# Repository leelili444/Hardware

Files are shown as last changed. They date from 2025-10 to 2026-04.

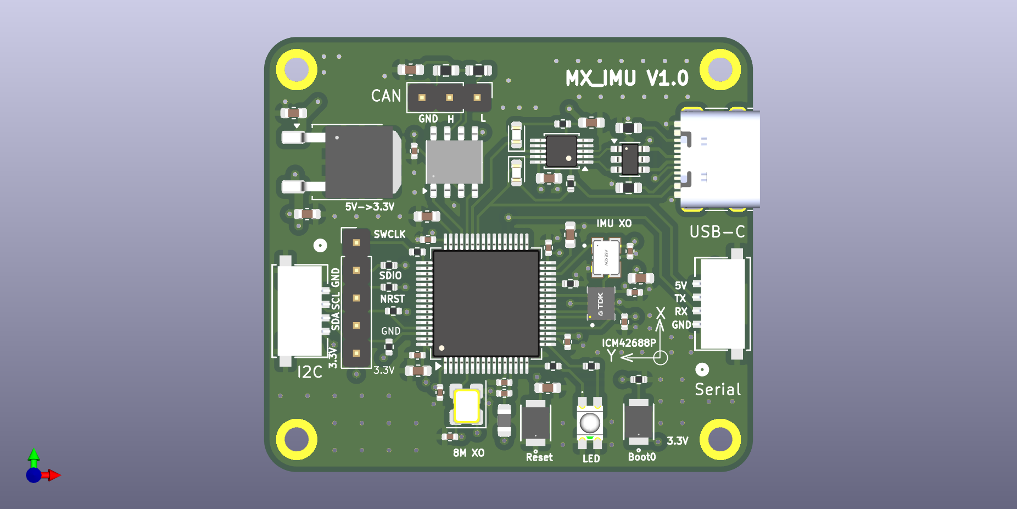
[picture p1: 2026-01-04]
production/MX_IMU.png

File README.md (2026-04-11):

# MX_IMU Hardware Design (using KiCad 9)

This repository contains the MX_IMU V1.0 hardware design files, libraries, and production outputs created with KiCad.

## Overview

- Project: MX_IMU (IMU sensor module)
- Tool: KiCad (schematic capture and PCB layout)

## Key Files

- `MX_IMU.kicad_pro` - Project file
- `MX_IMU.kicad_sch` — Main schematic
- `MX_IMU.kicad_pcb` — PCB layout file
- `*.kicad_sym` — Symbol files, located in `library/symbols`
- `*.kicad_mod` (footprints) — Footprint libraries, located in `library/footprints`
- `3DModels/` — Component 3D STEP models for the PCB 3D viewer
- `production/` — Manufacturing outputs (BOM, placement files, IPC netlist, etc.)

## How to Open

1. Install KiCad on your computer (stable or LTS versions recommended).
2. Open the project via `File -> Open Project` and select `MX_IMU.kicad_pro`, or open `MX_IMU.kicad_sch` / `MX_IMU.kicad_pcb` directly.

## Libraries and 3D Models

- Custom symbols: `library/symbols`.
- Custom footprints: `library/footprints` (contained in `.pretty` directories).
- 3D STEP files: `library/3DModels` for the PCB 3D viewer and manufacturing visualization.

## Production Directory

The `production/` directory includes `bom.csv`, `positions.csv` (placement), `netlist.ipc`, and similar files that can be used for ordering or manufacturing.
## License
oshw_facts

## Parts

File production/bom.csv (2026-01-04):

Designator | Footprint | Quantity | Value | LCSC Part #
C1, C16, C3 | 0603 | 3 | 100nf
C10, C11, C12, C15, C21, C7, C9 | 0402 | 7 | 100n | C1525
C13 | 0402 | 1 | 1u | C52923
C14 | 0402 | 1 | 10n | C15195
C17 | 0402 | 1 | 0.01u
C18 | 0402 | 1 | 0.1u
C19, C4, C6, C8 | 0603 | 4 | 2u2 | C23630
C2 | 0603 | 1 | 1u
C20 | 0402 | 1 | 10n
C22 | 0603 | 1 | 4n7
C5 | 0603 | 1 | 4u7 | C19666
D1, D2 | 0603 | 2 | LED
FB1 | 0805 | 1 | 600 @ 600 MHz | C1017
H1, H2, H3, H4 | MountingHole_2.2mm_M2_DIN965_Pad | 4 | MountingHole_Pad
I2C1, SERIAL1 | CONN_SM04B-GHS-TB_JST | 2 | SM04B-GHS-TB(LF)(SN)
J1 | USB_C_Receptacle_HRO_TYPE-C-31-M-12 | 1 | Serial USB
J2 | PinHeader_1x05_P2.54mm_Vertical | 1 | ZX-PZ2.54-1-5PZZ
J3 | PinHeader_1x03_P2.54mm_Vertical | 1 | Conn_01x03_Socket
LED1 | APBD3224SURKCGKCF01 | 1 | APBD3224SURKCGKC-F01
LSE1 | XTAL_ASEK-32.768KHZ-L-R-T | 1 | ASEK-32.768KHZ-L-R-T
R1, R2, R7, R8 | 0402 | 4 | 330R | C25104
R10, R11, R9 | 0402 | 3 | 22 | C25092
R12, R13 | 0603 | 2 | 60R | C166918
R14, R15 | 0402 | 2 | 2k2
R3, R4 | 0603 | 2 | 5.1k
R5, R6 | 0402 | 2 | 10k | C25744
SW1, SW2 | SW_B3U-1000P_OMR | 2 | B3U-1000P | C231329
U1 | MSOP-10_3x3mm_P0.5mm | 1 | CH340E
U2 | to-252-2_dpak-2-leg | 1 | ld39150dt33-r
U3 | SOT-23-6 | 1 | USBLC6-2SC6
U4 | LQFP-64_10x10mm_P0.5mm | 1 | STM32F405RGTx | C15742
U5 | Oscillator_SMD_SeikoEpson_SG3225CAN-4Pin_3.2x2.5mm | 1 | X1G0059610004 | X1G0059610004
U6 | ICM42688p | 1 | ICM-42688-P
U7 | sot96-1_soic-8 | 1 | TJA1051T/3

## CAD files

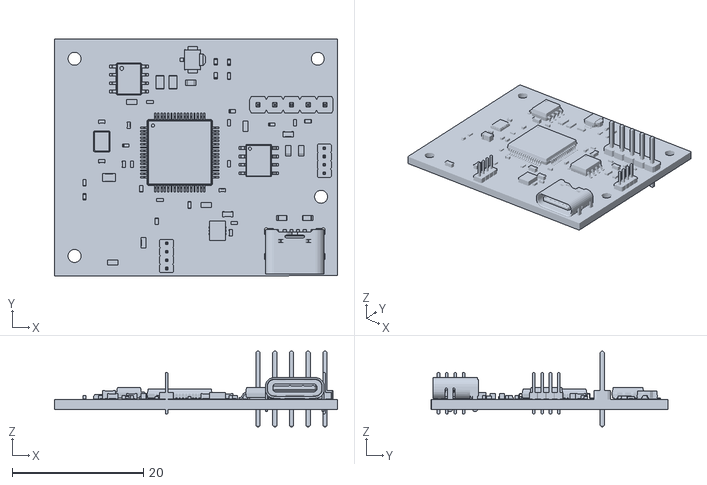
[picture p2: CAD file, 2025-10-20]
MX_IMU.stl
43.1 x 36.1 x 11.5

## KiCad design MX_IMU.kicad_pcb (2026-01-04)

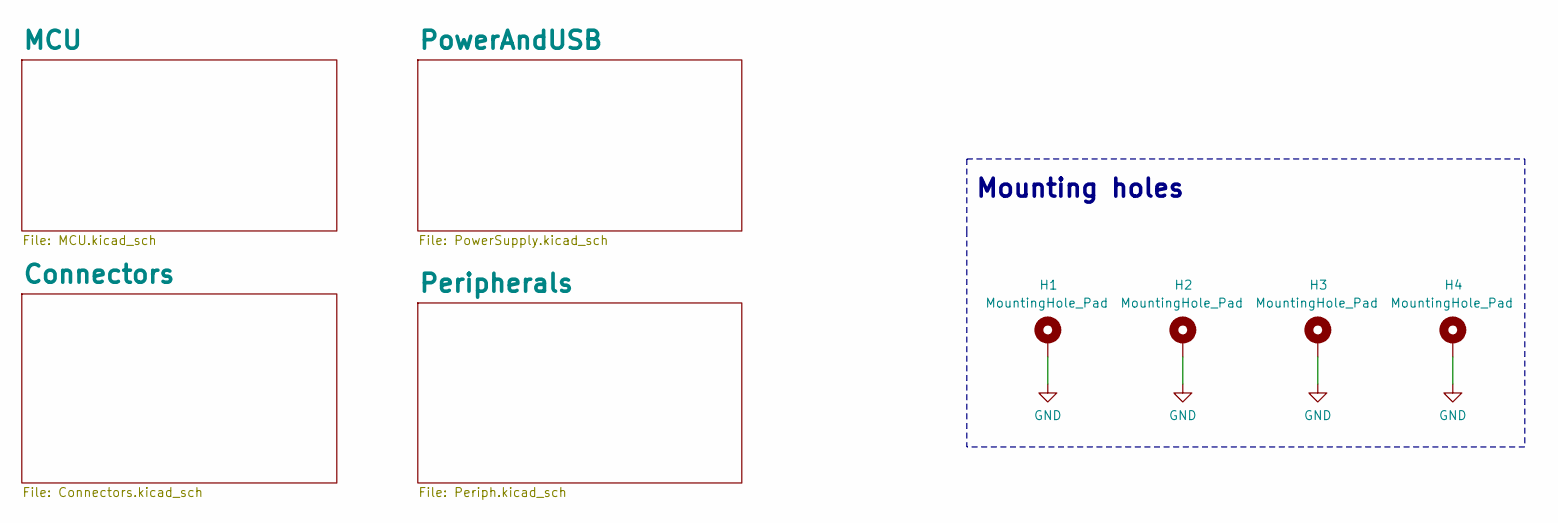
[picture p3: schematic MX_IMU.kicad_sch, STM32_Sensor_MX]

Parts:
H1, H2, H3, H4: MountingHole_Pad; MountingHole_2.2mm_M2_DIN965_Pad

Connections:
GND: H1.1, H2.1, H3.1, H4.1; also elsewhere on the board

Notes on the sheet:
Mounting holes

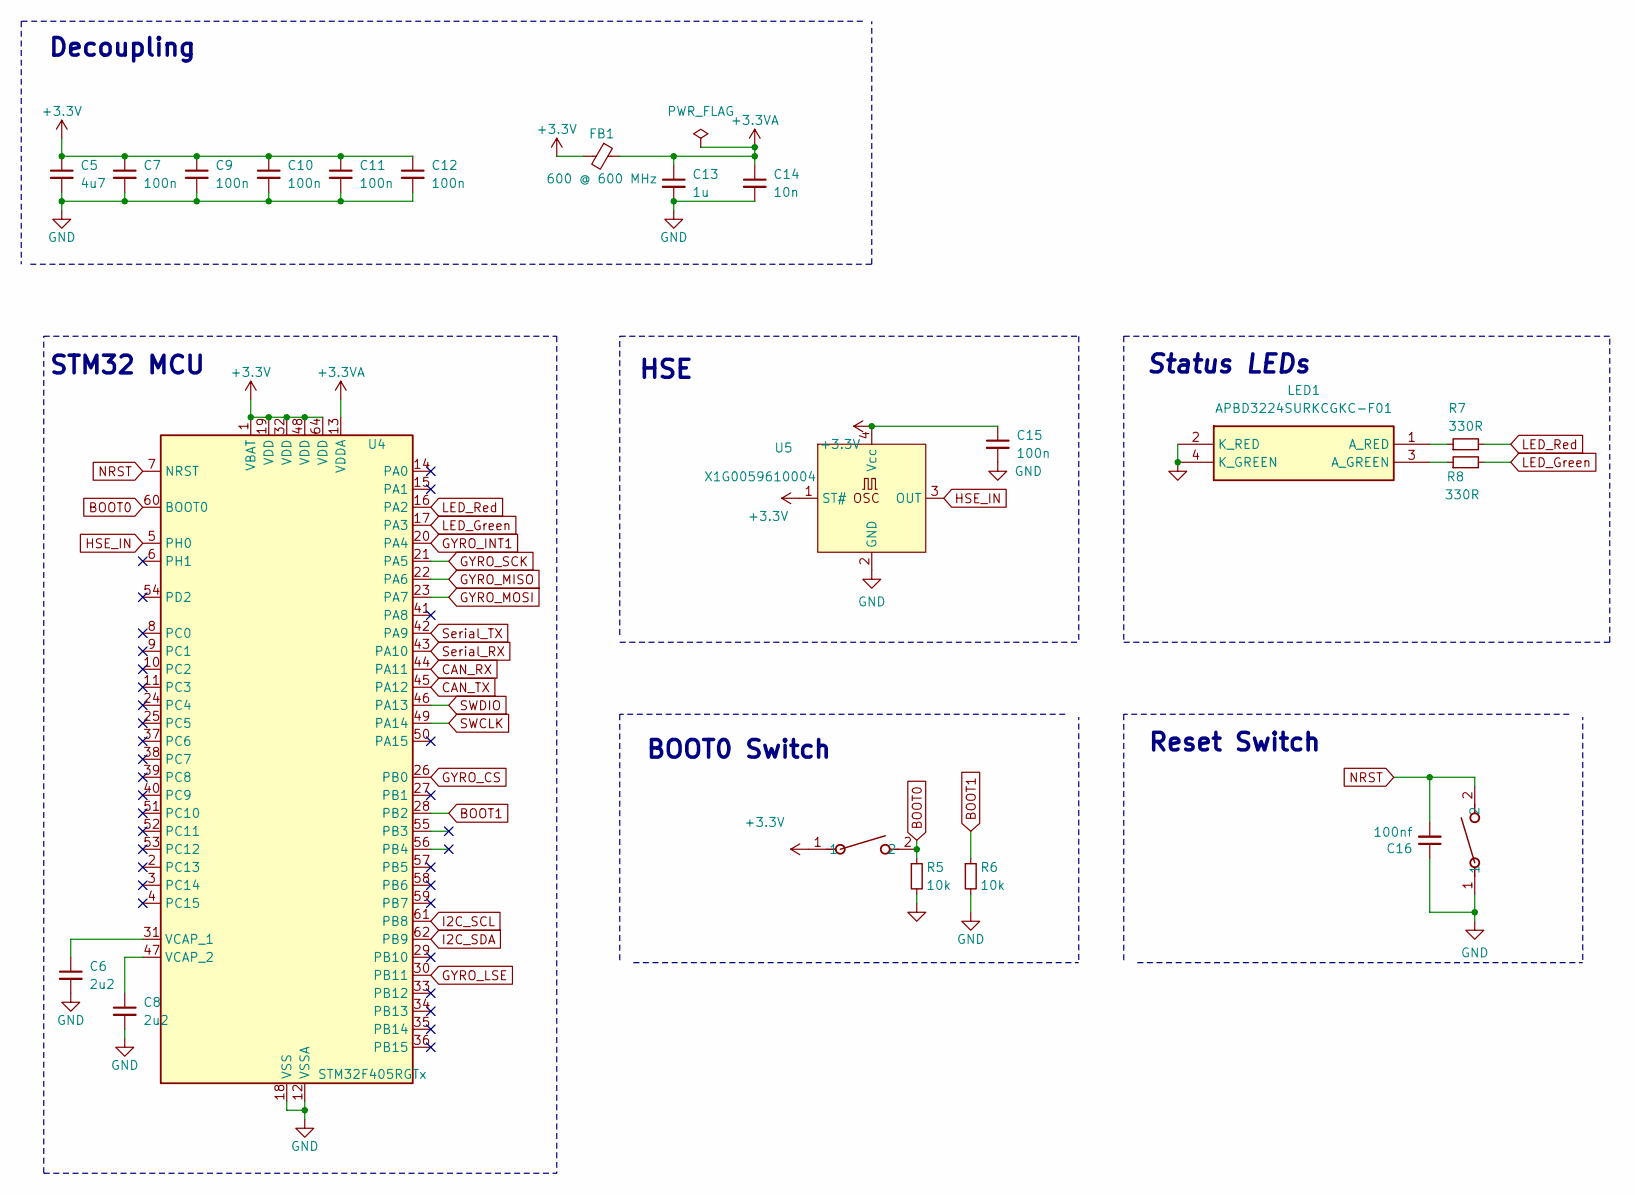
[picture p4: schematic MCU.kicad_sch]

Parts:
C5: 4u7; C_0603_1608Metric; LCSC Part # C19666
C6, C8: 2u2; C_0603_1608Metric; LCSC Part # C23630
C7, C9, C10, C11, C12, C15: 100n; C_0402_1005Metric; LCSC Part # C1525
C13: 1u; C_0402_1005Metric; LCSC Part # C52923
C14: 10n; C_0402_1005Metric; LCSC Part # C15195
C16: 100nf; C_0603_1608Metric
FB1: 600 @ 600 MHz; L_0805_2012Metric; LCSC Part # C1017
LED1: APBD3224SURKCGKC-F01; APBD3224SURKCGKCF01; Manufacturer_Part_Number APBD3224SURKCGKC-F01; Mouser Part Number 604-APBD3224SURKCGKC
R5, R6: 10k; R_0402_1005Metric; LCSC Part # C25744
R7, R8: 330R; R_0402_1005Metric; LCSC Part # C25104
SW1, SW2: B3U-1000P; SW_B3U-1000P_OMR; JLCPCB Part C231329
U4: STM32F405RGTx; LQFP-64_10x10mm_P0.5mm; LCSC Part # C15742
U5: X1G0059610004; Oscillator_SMD_SeikoEpson_SG3225CAN-4Pin_3.2x2.5mm; MPN X1G0059610004; LCSC Part C7504299

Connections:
+3.3V: C5.1, C7.1, C9.1, C10.1, C11.1, C12.1, C15.1, FB1.2, SW1.1, U4.1 (VBAT), U4.19 (VDD), U4.32 (VDD), U4.48 (VDD), U4.64 (VDD), U5.1 (ST#), U5.4 (Vcc); also elsewhere on the board
+3.3VA: C13.1, C14.1, FB1.1, U4.13 (VDDA)
BOOT0: R5.1, SW1.2, U4.60 (BOOT0)
BOOT1: R6.1, U4.28 (PB2)
CAN_RX: U4.44 (PA11); also elsewhere on the board
CAN_TX: U4.45 (PA12); also elsewhere on the board
GND: C5.2, C6.2, C7.2, C8.2, C9.2, C10.2, C11.2, C12.2, C13.2, C14.2, C15.2, C16.1, LED1.2 (K_RED), LED1.4 (K_GREEN), R5.2, R6.2, SW2.1, U4.12 (VSSA), U4.18 (VSS), U4.63 (VSS), U5.2 (GND); also elsewhere on the board
GYRO_CS: U4.26 (PB0); also elsewhere on the board
GYRO_INT1: U4.20 (PA4); also elsewhere on the board
GYRO_LSE: U4.30 (PB11); also elsewhere on the board
GYRO_MISO: U4.22 (PA6); also elsewhere on the board
GYRO_MOSI: U4.23 (PA7); also elsewhere on the board
GYRO_SCK: U4.21 (PA5); also elsewhere on the board
HSE_IN: U4.5 (PH0), U5.3 (OUT)
I2C_SCL: U4.61 (PB8); also elsewhere on the board
I2C_SDA: U4.62 (PB9); also elsewhere on the board
LED_Green: R8.2, U4.17 (PA3)
LED_Red: R7.2, U4.16 (PA2)
NRST: C16.2, SW2.2, U4.7 (NRST); also elsewhere on the board
unnamed: LED1.3 (A_GREEN), R8.1
unnamed: LED1.1 (A_RED), R7.1
unnamed: C6.1, U4.31 (VCAP_1)
unnamed: C8.1, U4.47 (VCAP_2)
SWCLK: U4.49 (PA14); also elsewhere on the board
SWDIO: U4.46 (PA13); also elsewhere on the board
Serial_RX: U4.43 (PA10); also elsewhere on the board
Serial_TX: U4.42 (PA9); also elsewhere on the board

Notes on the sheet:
HSE
Reset Switch
Status LEDs
Decoupling
BOOT0 Switch
STM32 MCU

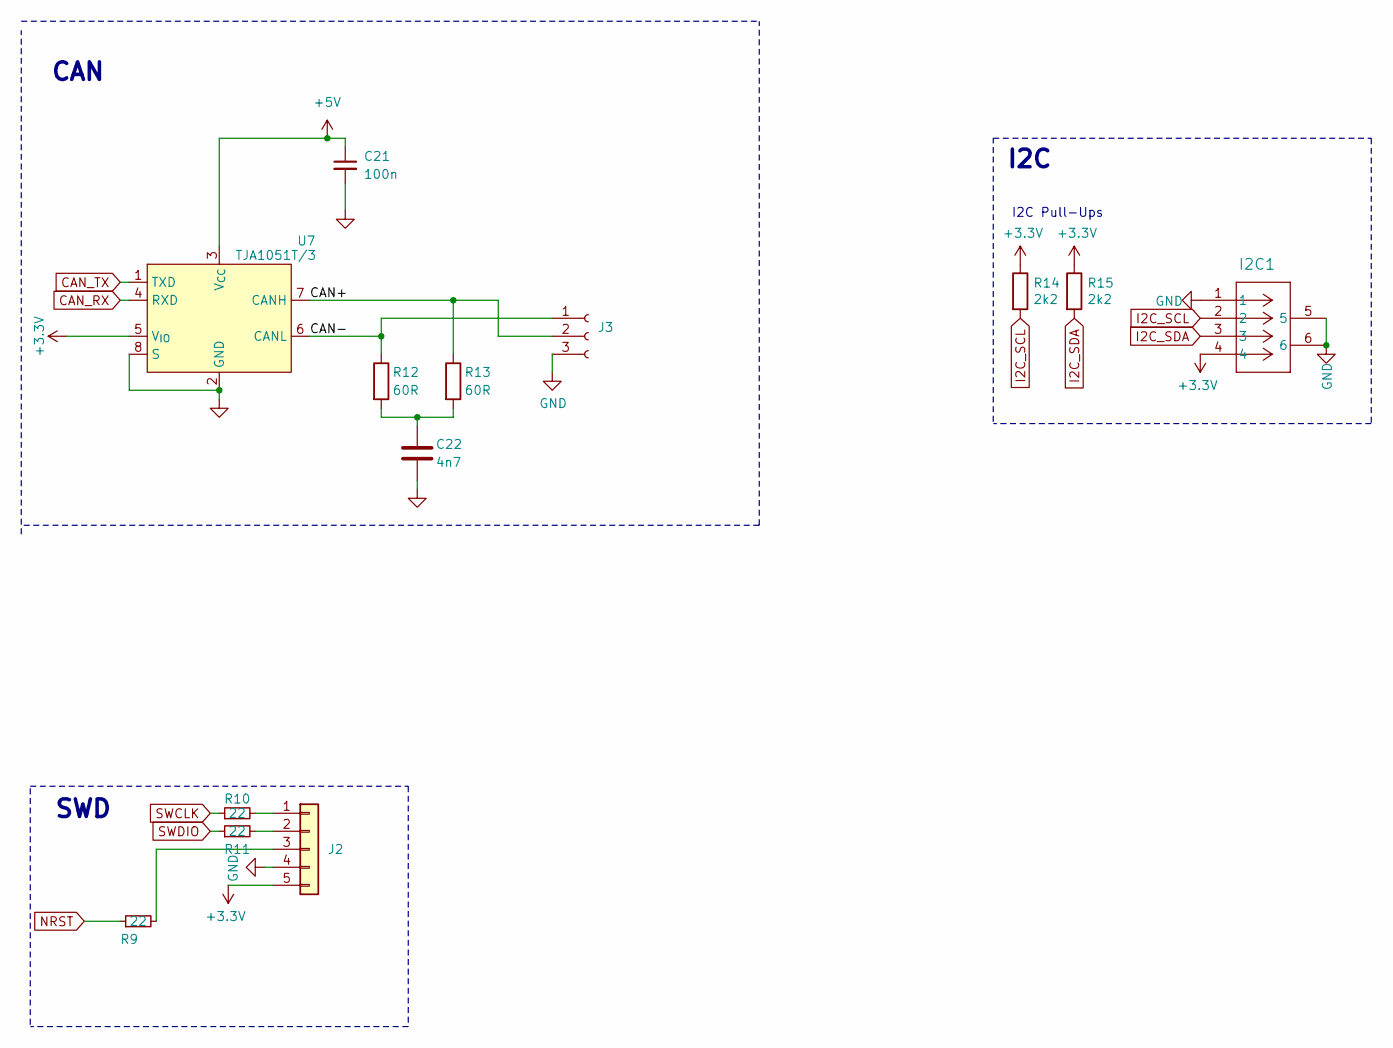
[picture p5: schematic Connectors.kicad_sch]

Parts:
C21: 100n; C_0402_1005Metric; LCSC Part # C1525
C22: 4n7; C_0603_1608Metric
I2C1: SM04B-GHS-TB(LF)(SN); CONN_SM04B-GHS-TB_JST
J2: ZX-PZ2.54-1-5PZZ; PinHeader_1x05_P2.54mm_Vertical
J3: Conn_01x03_Socket; PinHeader_1x03_P2.54mm_Vertical
R9, R10, R11: 22; R_0402_1005Metric; LCSC Part # C25092
R12: 60R; R_0603_1608Metric; LCSC Part C166918
R13: 60R; R_0603_1608Metric; LCSC C166918
R14, R15: 2k2; R_0402_1005Metric
U7: TJA1051T/3; sot96-1_soic-8; Manufacturer Part Number TJA1051T/3

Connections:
+3.3V: I2C1.4, J2.5, R14.1, R15.1, U7.5 (V_{IO}); also elsewhere on the board
+5V: C21.1, U7.3 (V_{CC}); also elsewhere on the board
/Connectors/CAN+: J3.2, R13.1, U7.7 (CANH)
/Connectors/CAN-: J3.1, R12.1, U7.6 (CANL)
CAN_RX: U7.4 (RXD); also elsewhere on the board
CAN_TX: U7.1 (TXD); also elsewhere on the board
GND: C21.2, C22.2, I2C1.1, I2C1.5, I2C1.6, J2.4, J3.3, U7.2 (GND), U7.8 (S); also elsewhere on the board
I2C_SCL: I2C1.2, R14.2; also elsewhere on the board
I2C_SDA: I2C1.3, R15.2; also elsewhere on the board
NRST: R9.1; also elsewhere on the board
unnamed: C22.1, R12.2, R13.2
unnamed: J2.1, R10.2
unnamed: J2.2, R11.2
unnamed: J2.3, R9.2
SWCLK: R10.1; also elsewhere on the board
SWDIO: R11.1; also elsewhere on the board

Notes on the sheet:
I2C Pull-Ups
CAN
SWD
I2C

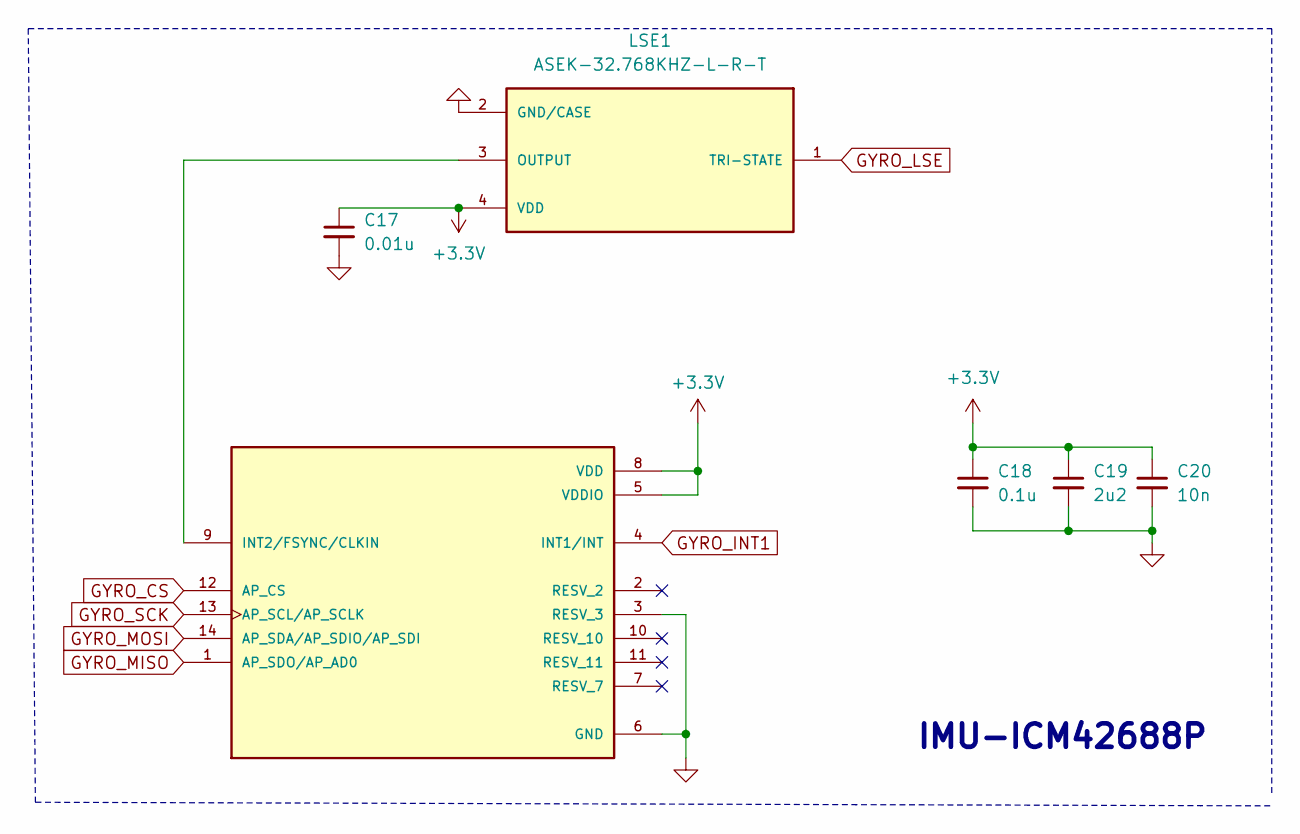
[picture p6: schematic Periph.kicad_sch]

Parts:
C17: 0.01u; C_0402_1005Metric
C18: 0.1u; C_0402_1005Metric
C19: 2u2; C_0603_1608Metric; LCSC Part # C23630
C20: 10n; C_0402_1005Metric
LSE1: ASEK-32.768KHZ-L-R-T; XTAL_ASEK-32.768KHZ-L-R-T; PARTREV 01-11-22; LCSC Part C2650753 C5280579
U6: ICM-42688-P; ICM42688p; PARTREV 1.2

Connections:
+3.3V: C17.1, C18.1, C19.1, C20.1, LSE1.4 (VDD), U6.5 (VDDIO), U6.8 (VDD); also elsewhere on the board
GND: C17.2, C18.2, C19.2, C20.2, LSE1.2 (GND/CASE), U6.3 (RESV_3), U6.6 (GND); also elsewhere on the board
GYRO_CS: U6.12 (AP_CS); also elsewhere on the board
GYRO_INT1: U6.4 (INT1/INT); also elsewhere on the board
GYRO_LSE: LSE1.1 (TRI-STATE); also elsewhere on the board
GYRO_MISO: U6.1 (AP_SDO/AP_AD0); also elsewhere on the board
GYRO_MOSI: U6.14 (AP_SDA/AP_SDIO/AP_SDI); also elsewhere on the board
GYRO_SCK: U6.13 (AP_SCL/AP_SCLK); also elsewhere on the board
unnamed: LSE1.3 (OUTPUT), U6.9 (INT2/FSYNC/CLKIN)

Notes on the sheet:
IMU-ICM42688P

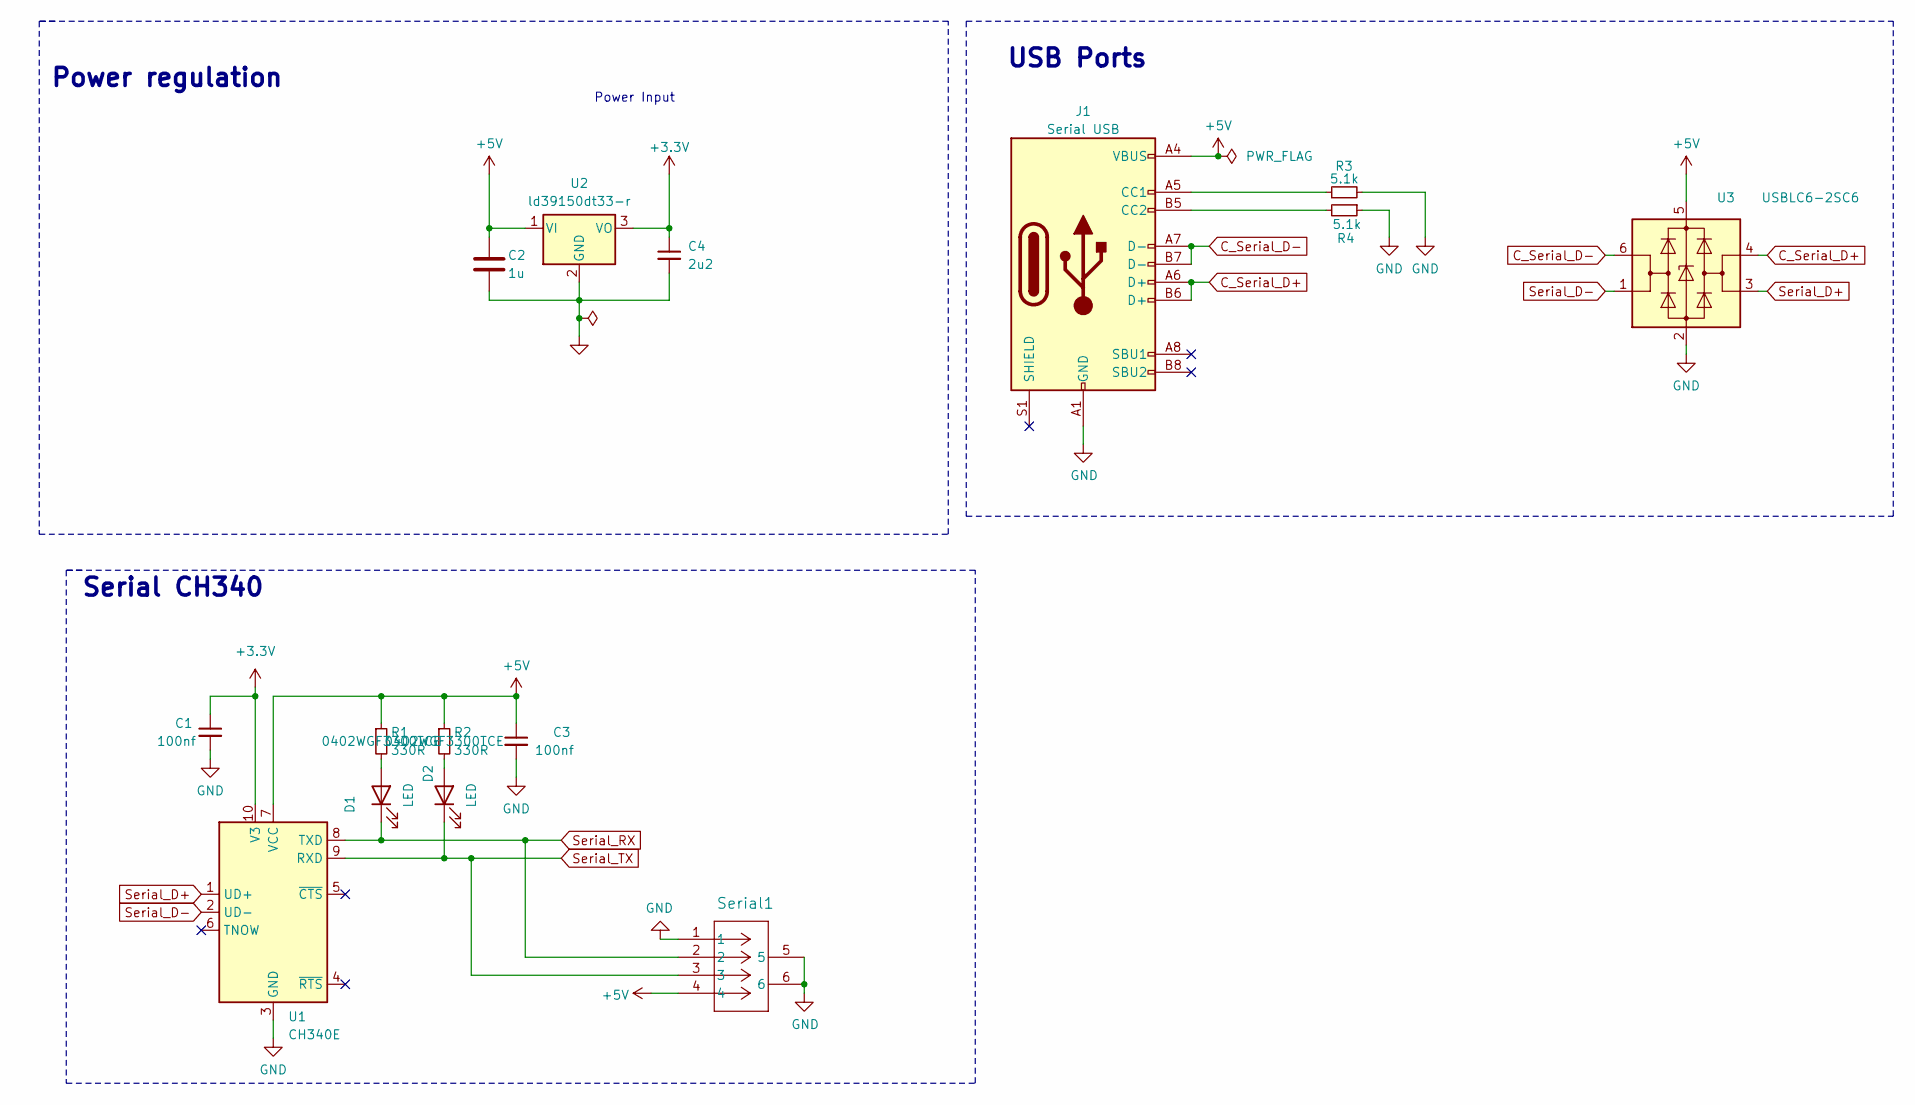
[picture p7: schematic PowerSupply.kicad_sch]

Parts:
C1, C3: 100nf; C_0603_1608Metric
C2: 1u; C_0603_1608Metric; JLCPCB part C15849
C4: 2u2; C_0603_1608Metric; LCSC Part # C23630
D1: LED; LED_0603_1608Metric; Manufacturer Part LTST-S270KGKT
D2: LED; LED_0603_1608Metric; Manufacturer Part LTST-S270KRKT
J1: Serial USB; USB_C_Receptacle_HRO_TYPE-C-31-M-12
R1, R2: 330R; R_0402_1005Metric; LCSC Part # C25104
R3, R4: 5.1k; R_0603_1608Metric
Serial1: SM04B-GHS-TB(LF)(SN); CONN_SM04B-GHS-TB_JST
U1: CH340E; MSOP-10_3x3mm_P0.5mm
U2: ld39150dt33-r; to-252-2_dpak-2-leg; Manufacturer Part Number LD39150DT33-R
U3: USBLC6-2SC6; SOT-23-6

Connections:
+3.3V: C1.1, C4.1, U1.10 (V3), U2.3 (VO); also elsewhere on the board
+5V: C2.1, C3.1, J1.A4 (VBUS), J1.A9 (VBUS), J1.B4 (VBUS), J1.B9 (VBUS), R1.1, R2.1, Serial1.4, U1.7 (VCC), U2.1 (VI), U3.5 (VBUS); also elsewhere on the board
C_Serial_D+: J1.A6 (D+), J1.B6 (D+), U3.4 (I/O2)
C_Serial_D-: J1.A7 (D-), J1.B7 (D-), U3.6 (I/O1)
GND: C1.2, C2.2, C3.2, C4.2, J1.A1 (GND), J1.A12 (GND), J1.B1 (GND), J1.B12 (GND), R3.2, R4.1, Serial1.1, Serial1.5, Serial1.6, U1.3 (GND), U2.2 (GND), U3.2 (GND); also elsewhere on the board
unnamed: D1.2 (A), R1.2
unnamed: D2.2 (A), R2.2
unnamed: J1.A5 (CC1), R3.1
unnamed: J1.B5 (CC2), R4.2
Serial_D+: U1.1 (UD+), U3.3 (I/O2)
Serial_D-: U1.2 (UD-), U3.1 (I/O1)
Serial_RX: D1.1 (K), Serial1.2, U1.8 (TXD); also elsewhere on the board
Serial_TX: D2.1 (K), Serial1.3, U1.9 (RXD); also elsewhere on the board

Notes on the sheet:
USB Ports
Power Input
Serial CH340
Power regulation

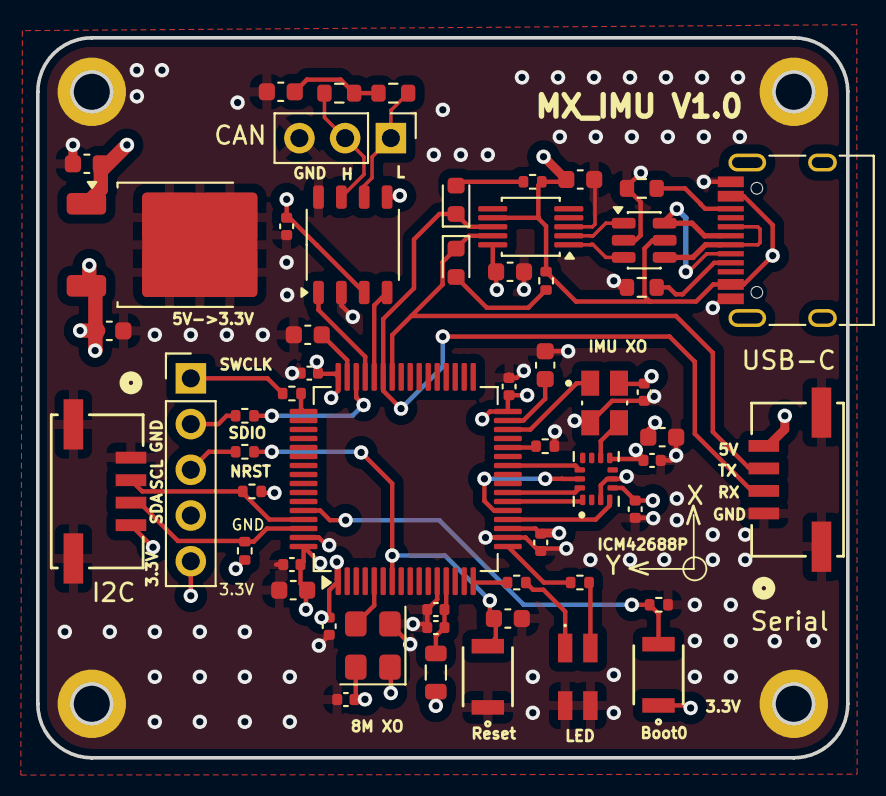
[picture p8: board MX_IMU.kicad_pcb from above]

Board: 4 copper layers, 45.0 x 40.0 mm, 60 parts (0 on the bottom side), 43 nets.

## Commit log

2025-10-20 update pcb
    [Connectors.kicad_sch, MX_IMU.kicad_pcb, MX_IMU.kicad_sch]
2025-10-23 update spi flash and ws2812b
    [MCU.kicad_sch, Periph.kicad_sch]
2025-10-23 update library
    [2169900001.stp, 2171750001.stp, 353630460.stp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]
2025-10-23 clean files
    [Connectors.kicad_sch, MX_IMU.kicad_pcb, Periph.kicad_sch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]
2025-10-26 update value for capacity and resistor
    [Connectors.kicad_sch, MCU.kicad_sch, MX_IMU.kicad_pcb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]
2025-10-26 update pcb and imu 3d model
    [MCU.kicad_sch, MX_IMU.kicad_pcb]
2026-01-04 update V2_RC1
    [Connectors.kicad_sch, MCU.kicad_sch, Periph.kicad_sch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]
2026-01-04 compact IMU module for integration
    [Connectors.kicad_sch, MCU.kicad_sch, MX_IMU.kicad_pcb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]
2026-01-04 IMU_IMU V1.0 is ready.
    correct ch340e
    [Connectors.kicad_sch, MCU.kicad_sch, MX_IMU.kicad_pcb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]
2026-01-04 clean up
    [bom.csv]
